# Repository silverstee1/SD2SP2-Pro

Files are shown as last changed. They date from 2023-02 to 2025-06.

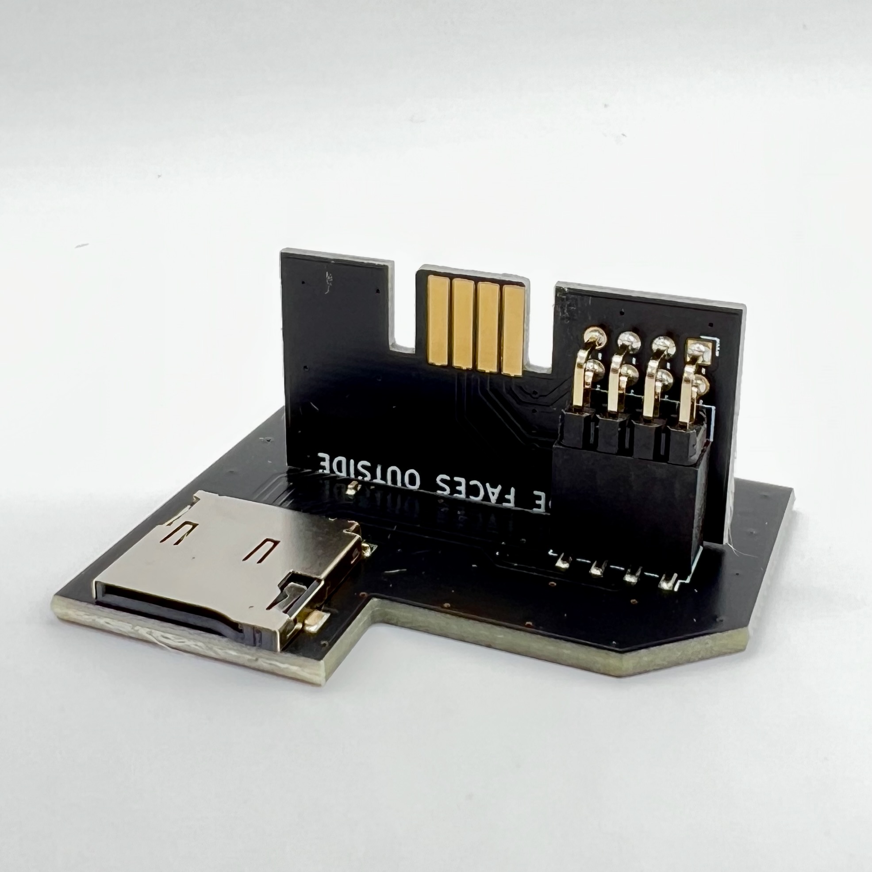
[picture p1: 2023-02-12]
Assets/assembly.jpeg

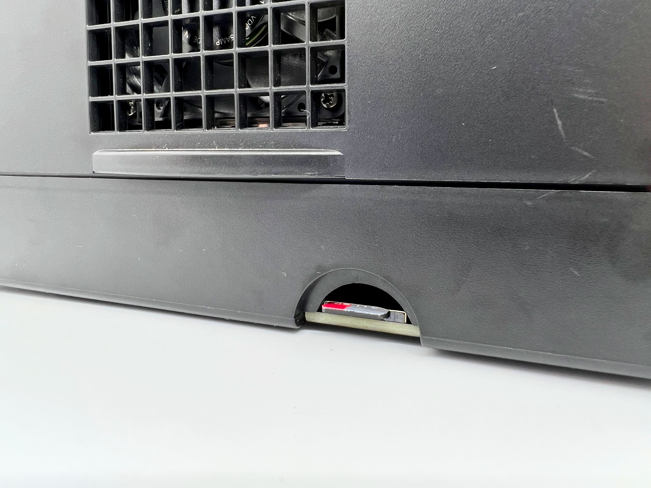
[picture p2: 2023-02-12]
Assets/side.jpg

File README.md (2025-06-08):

The inside PCB must be ordered in 1.2mm thickness. Surface finish must be ENIG at minimum.

The outside PCB must be ordered in 2.0mm thickness.

I recommend https://jlcpcb.com for PCB production.

***Occasionally when receiving the pcb's from JLCPCB the outside pcb may have a bump/not flush cut near the SP1 side when it was cut at the fab and might require sanding to smooth it out for a better fit.***

***Included is a stl cover in the 2.0 project folder that fits flush with the outside pcb***

# SD2SP2 Pro 2.0

pcb1-min

pcb2-min

SD2SP2 PRO 2.0 BOM
=====================================
The inside PCB must be ordered in 1.2mm thickness. Surface finish must be ENIG at minimum.

The outside PCB must be ordered in 2.0mm thickness.

**Outside PCB**

**C1:** 0402 22u Capactior (10V Min) - DigiKey Part# 490-GRM158R61A226ME15DCT-ND

LCSC Part# C3845593

**J2:** 02x04 2.54mm Female Pin Socket - DigiKey Part# SSW-104-22-F-D-VS-K-TR

LCSC Part# C5160819

**J3:** MicroSD Slot - DigiKey Part# 2223-MSD-4-ACT-ND

LCSC Part# C113206

**U1:** OR Gate IC - DigiKey Part# 296-1093-1-ND

LCSC Part# C7470

Alt Nexperia Digikey Part# 1727-3067-1-ND

LCSC Alt Nexperia Part# C12488

**Inside PCB**

**J1:** 02x04 2.54mm Male Right Angle Pin Header - DigiKey Part# 10129382-908002BLF-ND

LCSC Part# C492432

Special thanks to:
=====================================
 * citrus3000psi for the original project
 * MockyLock for the idea
 * misteraddons for the SD2SP2 PRO  
 * Extrems & emu_kidid for doing the real work needed to make this possible

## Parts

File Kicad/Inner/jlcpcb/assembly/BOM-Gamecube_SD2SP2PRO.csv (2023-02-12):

Comment | Designator | Footprint | LCSC
Conn_02x04_Odd_Even | J1 | PinHeader_2x04_P2.54mm_Horizontal | C492432
SerialPort | P1 | SP2_FootPrint

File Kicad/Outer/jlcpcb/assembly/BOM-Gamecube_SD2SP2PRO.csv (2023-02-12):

Comment | Designator | Footprint | LCSC
Micro_SD_Card | J3 | Micro_SD_C113206 | C113206
100n | C1 | C_0402_1005Metric | C1525
Conn_02x04_Odd_Even | J2 | PinSocket_2x04_P2.54mm_Vertical_SMD | C5160819

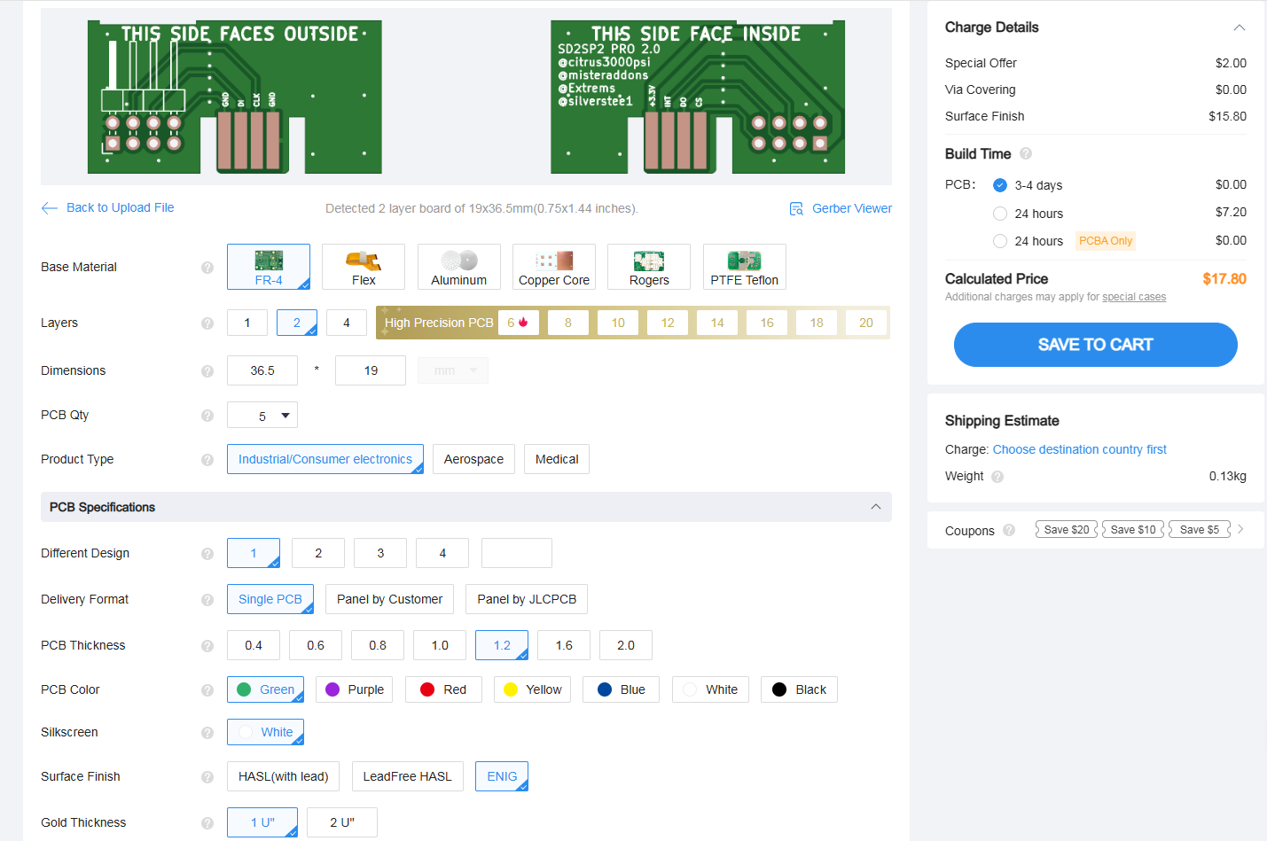
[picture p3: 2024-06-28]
SD2SP2-Pro 2.0/SD2SP2 Pro 2.0 Gerbers/JLCPCB Inner PCB Order Example.png

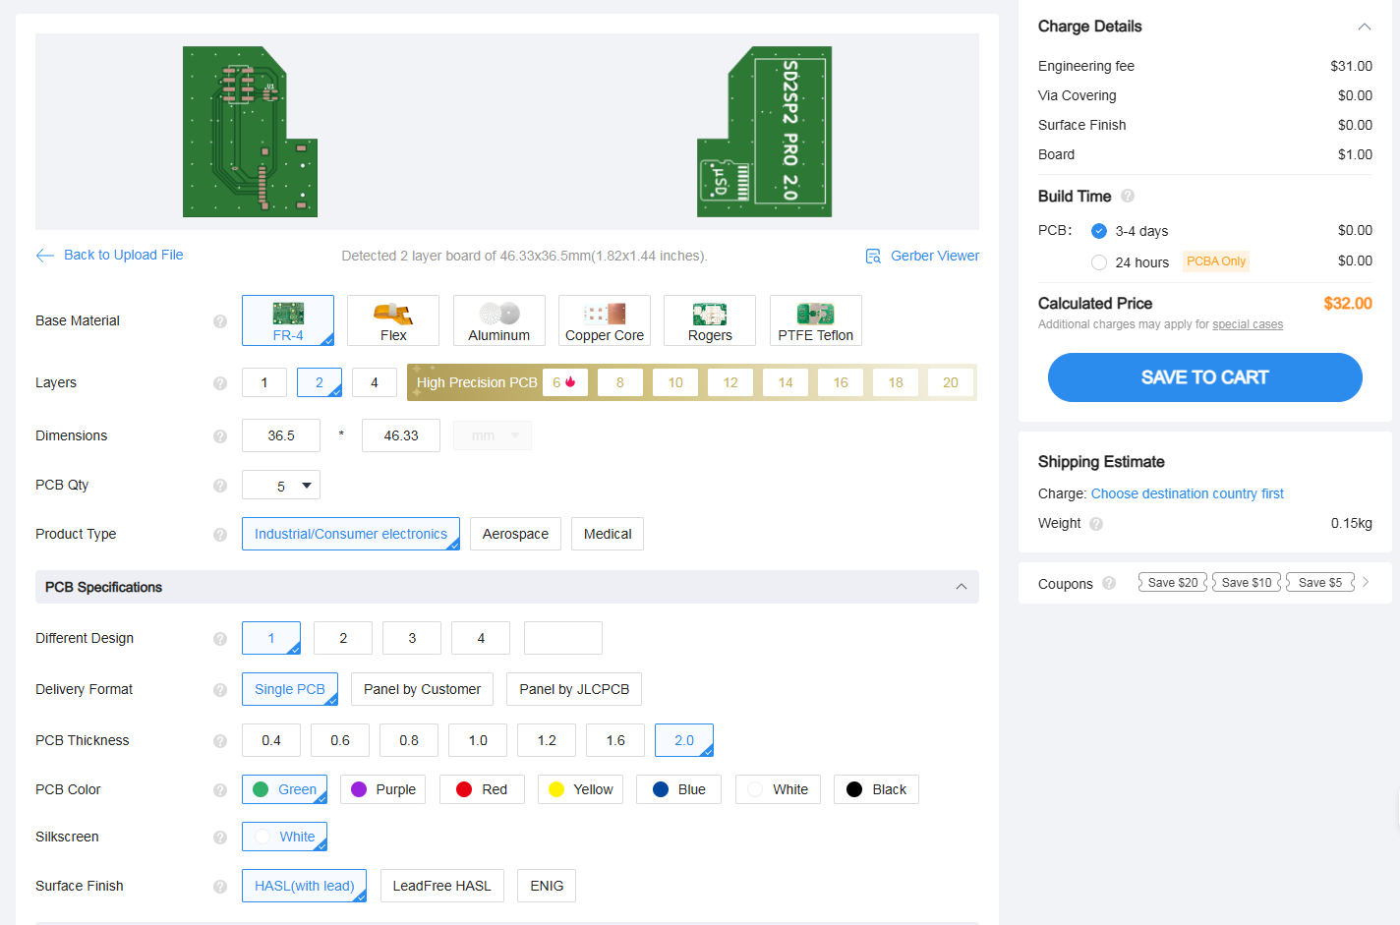
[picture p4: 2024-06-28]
SD2SP2-Pro 2.0/SD2SP2 Pro 2.0 Gerbers/JLCPCB Outer PCB Order Example.png

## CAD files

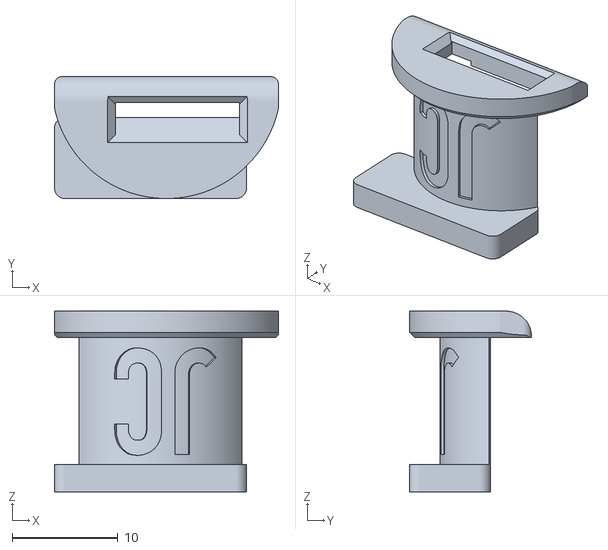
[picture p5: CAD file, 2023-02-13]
Cover/GC SD2SP2 PRO Pork.stl
21.2 x 11.6 x 17.1

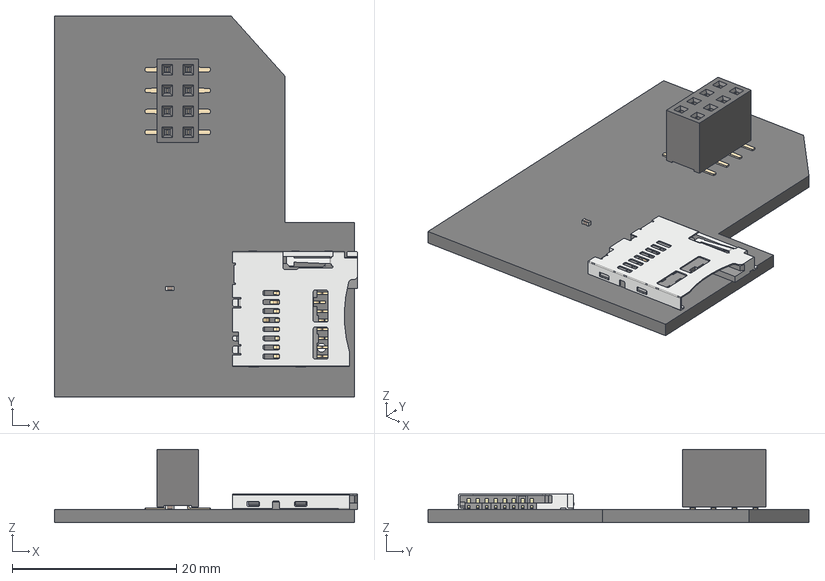
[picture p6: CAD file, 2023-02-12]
Kicad/Outer/Gamecube_SD2SP2PRO-Gamecube_SD2SP2PRO.step
36.9 x 46.3 x 8.90 mm
Local_CS_527a
Pcb_527a
PCB_Sketch_527a
C1_C_0402_1005Metric_00005bbdd2da
J2_PinSocket_2x04_P254mm_Vertical_SMD_b7ac2868619c
J3_473521001_microSD_485e4b754b6d

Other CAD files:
SD2SP2-Pro 2.0/STL Cover/SD2SP2 Cover.stl

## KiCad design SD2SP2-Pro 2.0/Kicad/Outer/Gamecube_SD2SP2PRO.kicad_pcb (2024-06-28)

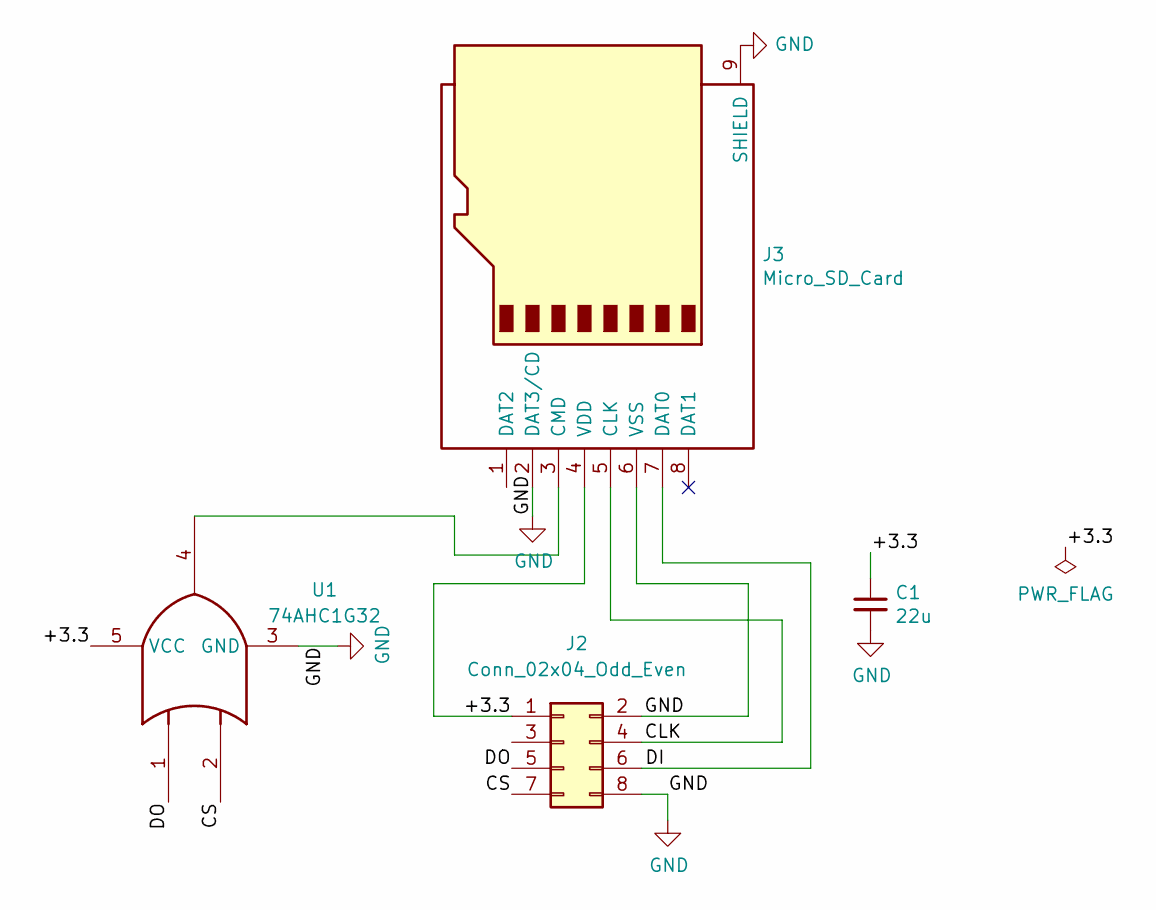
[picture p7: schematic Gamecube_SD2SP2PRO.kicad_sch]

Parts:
C1: 22u; C_0402_1005Metric; LCSC Part C1525
J2: Conn_02x04_Odd_Even; PinSocket_2x04_P2.54mm_Vertical_SMD; LCSC Part C5160819
J3: Micro_SD_Card; Micro_SD_C113206; LCSC Part C113206
U1: 74AHC1G32; SC-74A-5_1.55x2.9mm_P0.95mm; LCSC Part C12488

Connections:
/+3.3: C1.1, J2.1, J3.4 (VDD), U1.5 (VCC)
/CLK: J2.4, J3.5 (CLK)
/CS: J2.7, U1.2
/DI: J2.6, J3.7 (DAT0)
/DO: J2.5, U1.1
GND: C1.2, J2.2, J2.8, J3.2 (DAT3/CD), J3.6 (VSS), J3.9 (SHIELD), U1.3 (GND)
unnamed: J3.3 (CMD), U1.4

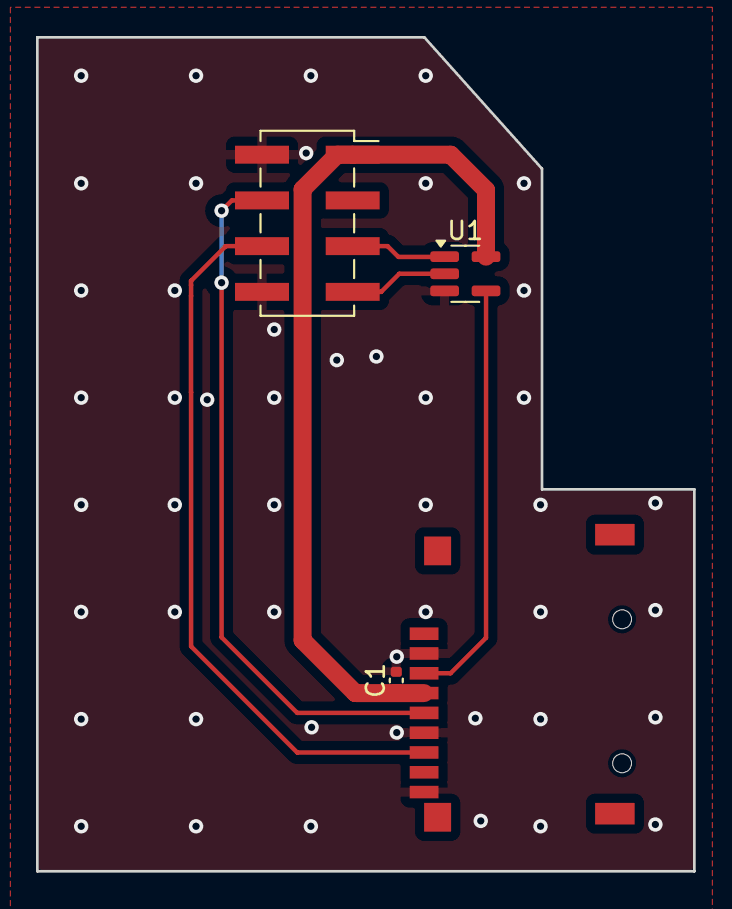
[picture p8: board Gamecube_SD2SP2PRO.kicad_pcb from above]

Board: 2 copper layers, 36.5 x 46.3 mm, 4 parts (0 on the bottom side), 7 nets.

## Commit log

2023-02-13 Create GC SD2SP2 PRO Pork.stl
    [GC SD2SP2 PRO Pork.stl]
2024-06-28 updated SD2SP2 Pro 2.0
    added pcb gerbers and updated project files in separate SD2SP2-Pro 2.0 folder
    [Gamecube_SD2SP2PRO.kicad_pcb, Gamecube_SD2SP2PRO.kicad_sch]
2024-06-28 Outer PCB changes
    fixed silkscreen for C1 and moved C1 closer to MicroSD Slot
2024-06-28 Outer Board C1 Silkscreen and relocation
    Moved C1 closer to MicroSD slot and fixed C1 Silkscreen layer
    [Gamecube_SD2SP2PRO.kicad_pcb]
2024-06-28 updated schematic
2024-06-28 added LCSC alt part#
    [Gamecube_SD2SP2PRO.kicad_pcb, Gamecube_SD2SP2PRO.kicad_sch]
2025-06-08 add SP2 port cover
    remixed from Jeff Chen's port cover
    [SD2SP2 Cover.stl]
